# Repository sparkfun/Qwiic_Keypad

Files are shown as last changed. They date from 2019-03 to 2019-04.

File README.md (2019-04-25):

SparkFun Qwiic KeyPad - 12 Button
========================================

SparkFun Qwiic Keypad

[*SparkFun Qwiic Keypad - 12 Button (COM-15290)*](https://www.sparkfun.com/products/15290)

Keypads are very handy input devices, but who wants to tie up seven GPIO pins, wire up a handful of pull-up resistors, and write firmware that wastes valuable processing time scanning the keys for inputs? The SparkFun Qwiic Keypad comes fully assembled and makes the development process for adding a 12 button keypad easy. No voltage translation or figuring out which I2C pin is SDA or SCL, just plug and go! Utilizing our handy Qwiic system, no soldering is required to connect it to the rest of your system. However, we still have broken out 0.1"-spaced pins in case you prefer to use a breadboard.

Each of the keypad's 12 buttons has been labeled 1, 2, 3, 4, 5, 6, 7, 8, 9, 0, *, and # and has been formatted to into the same layout as a telephone keypad with each keypress resistance ranging between 10 and 150 Ohms. The Qwiic Keypad reads and stores the last 15 button presses in a First-In, First-Out (FIFO) stack, so you don’t need to constantly poll the keypad from your microcontroller. This information, then, is accessible through the Qwiic interface. The SparkFun Qwiic Keypad even has a software configurable I2C address so you can have multiple I2C devices on the same bus.

Repository Contents
-------------------

* **/Firmware** - The core sketch that runs Qwiic Keypad
* **/Hardware** - Eagle design files (.brd, .sch)

Documentation
--------------
* **[Hookup Guide](https://learn.sparkfun.com/tutorials/qwiic-keypad-hookup-guide)** - Hookup Guide for the SparkFun Qwiic Keypad - 12 Button
* **[Product Showcase - YouTube Video](https://youtu.be/QPRrk0tHk08)** - Product showcase video with Rob Reynolds introducing the product and showing a few examples.
* **[Library](https://github.com/sparkfun/SparkFun_Qwiic_Keypad_Arduino_Library)** - Arduino library for the SparkFun Qwiic Keypad - 12 Button
* **[Installing an Arduino Library](https://learn.sparkfun.com/tutorials/installing-an-arduino-library/)** - Basic instructions on installing an Arduino library

Product Versions
--------------
* [COM-15290](https://www.sparkfun.com/products/15290) - SparkFun version
* [SPX-14836](https://www.sparkfun.com/products/retired/14836) - SparkX version

License Information
-------------------

This product is _**open source**_! 

Please review the LICENSE.md file for license information.

If you have any questions or concerns on licensing, please contact technical support on our [SparkFun forums](https://forum.sparkfun.com/viewforum.php?f=152).

Please use, reuse, and modify these files as you see fit. Please maintain attribution to SparkFun Electronics and release under the same license.

Distributed as-is; no warranty is given.

- Your friends at SparkFun.

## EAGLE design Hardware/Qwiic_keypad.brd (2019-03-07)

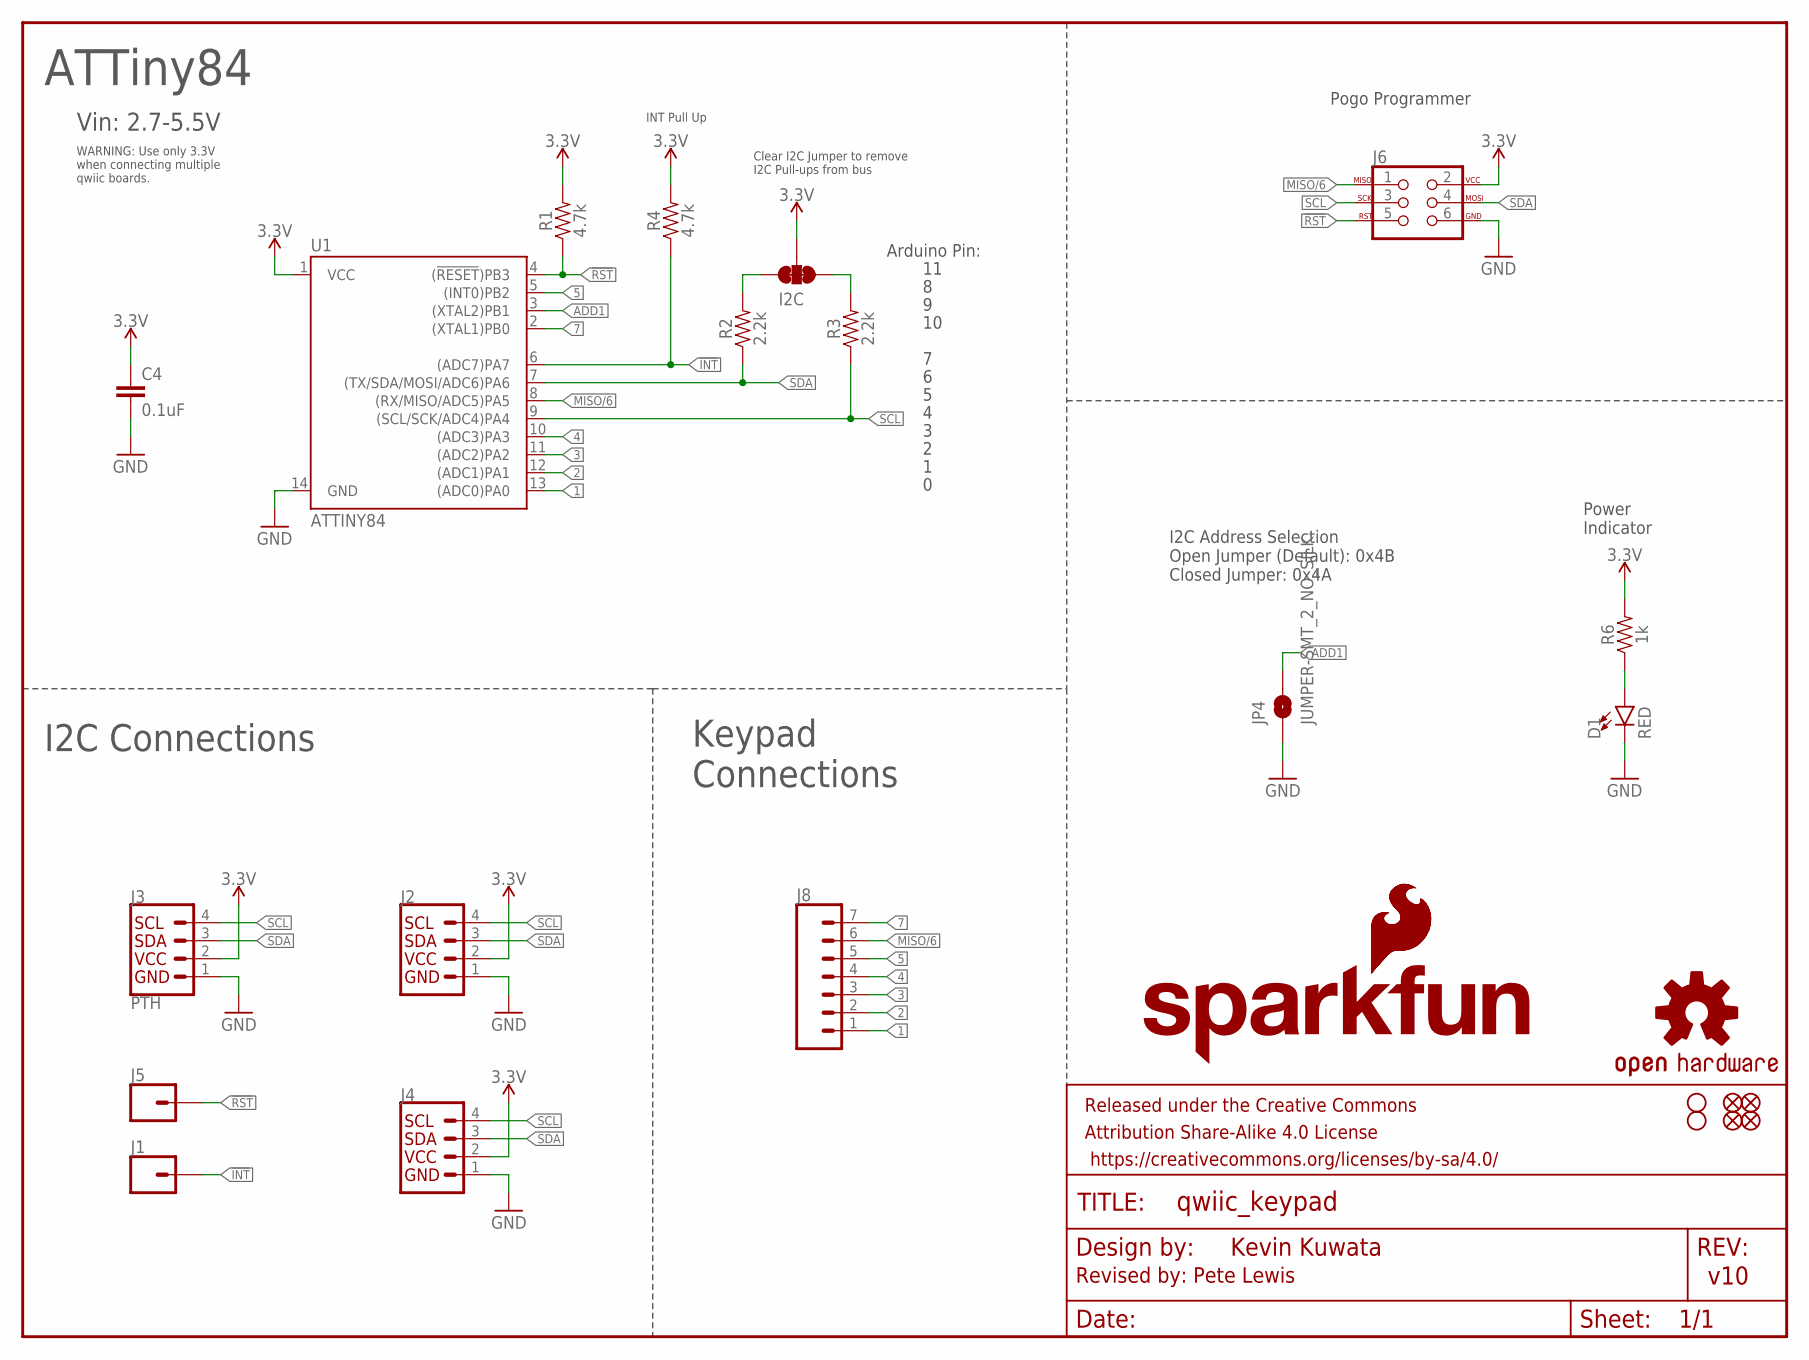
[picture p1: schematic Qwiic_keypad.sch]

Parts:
C4: 0.1uF; 0603
D1: RED; LED-0603
FRAME1: FRAME-LETTER; CREATIVE_COMMONS
H1, H2: STAND-OFF
I2C: JUMPER-SMT_3_2-NC_TRACE_SILK; SMT-JUMPER_3_2-NC_TRACE_SILK
J1, J5: CONN_01PTH_NO_SILK_YES_STOP; 1X01_NO_SILK
J2, J4: QWIIC_CONNECTORJS-1MM; JST04_1MM_RA
J3: PTH; 1X04_NO_SILK
J6: AVR_SPI_PROG_3X2TESTPOINTS; 2X3_TEST_POINTS
J8: CONN_07LOCK_NO_SILK; 1X07_LOCK_NO_SILK
JP1, JP2, JP3, JP6: FIDUCIALUFIDUCIAL; MICRO-FIDUCIAL
JP4: JUMPER-SMT_2_NO_SILK; SMT-JUMPER_2_NO_SILK
LOGO1: OSHW-LOGOMINI; OSHW-LOGO-MINI
LOGO2: SFE_LOGO_NAME_FLAME.1_INCH; SFE_LOGO_NAME_FLAME_.1
LOGO3: SFE_LOGO_FLAME.2_INCH; SFE_LOGO_FLAME_.2
R1, R4: 4.7k; 0603
R2, R3: 2.2k; 0603
R6: 1k; 0603
U1: ATTINY84; SO14

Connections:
1: J8.1, U1.13 ((ADC0)PA0)
2: J8.2, U1.12 ((ADC1)PA1)
3: J8.3, U1.11 ((ADC2)PA2)
3.3V: C4.1, I2C.2, J2.2, J3.2, J4.2, J6.2, R1.2, R4.2, R6.2, U1.1 (VCC)
4: J8.4, U1.10 ((ADC3)PA3)
5: J8.5, U1.5 ((INT0)PB2)
7: J8.7, U1.2 ((XTAL1)PB0)
!INT: J1.1, R4.1, U1.6 ((ADC7)PA7)
!RST: J5.1, J6.5, R1.1, U1.4 ((!RESET!)PB3)
ADD1: JP4.2, U1.3 ((XTAL2)PB1)
GND: C4.2, D1.C, J2.1, J3.1, J4.1, J6.6, JP4.1, U1.14 (GND)
MISO/6: J6.1, J8.6, U1.8 ((RX/MISO/ADC5)PA5)
unnamed: D1.A, R6.1
unnamed: I2C.3, R2.2
unnamed: I2C.1, R3.2
SCL: J2.4, J3.4, J4.4, J6.3, R3.1, U1.9 ((SCL/SCK/ADC4)PA4)
SDA: J2.3, J3.3, J4.3, J6.4, R2.1, U1.7 ((TX/SDA/MOSI/ADC6)PA6)

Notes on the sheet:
Kevin Kuwata
v10
I2C Address Selection Open Jumper (Default): 0x4B Closed Jumper: 0x4A
Power Indicator
Arduino Pin:
Revised by: Pete Lewis
INT Pull Up
Clear I2C Jumper to remove I2C Pull-ups from bus
ATTiny84
I2C Connections
Pogo Programmer
Vin: 2.7-5.5V
Keypad Connections
WARNING: Use only 3.3V when connecting multiple qwiic boards.

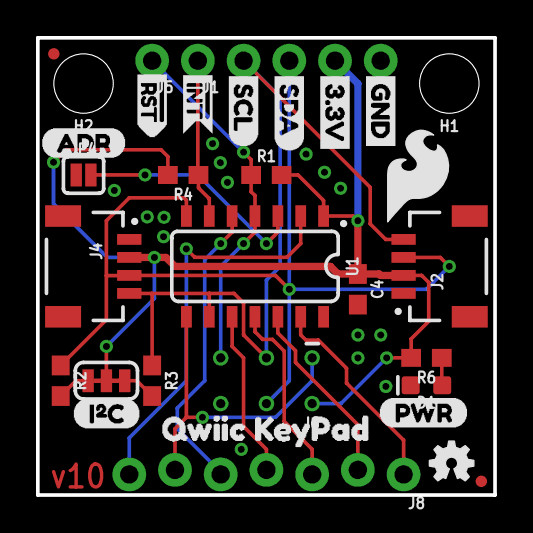
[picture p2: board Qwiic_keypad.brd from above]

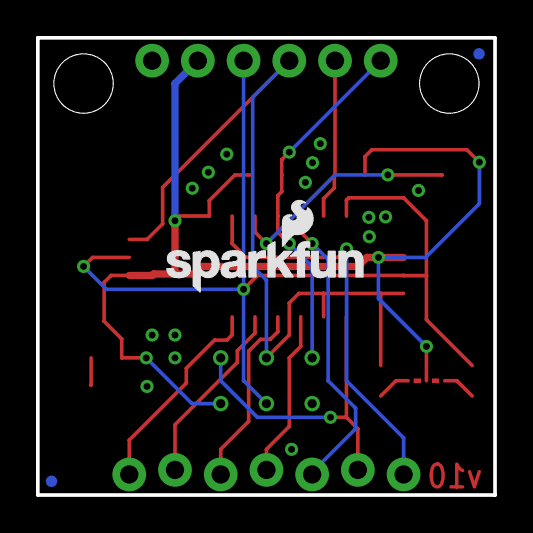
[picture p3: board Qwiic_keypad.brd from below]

Board: 2 copper layers, 25.4 x 25.4 mm, 37 parts (3 on the bottom side), 17 nets.

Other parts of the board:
U$3: 3.3V
U$4: GND
U$5: SDA
U$6: SCL
U$8: (PWR)
U$9: (I_SUPER2_C)
U$10: (ADR)
U$11: #RST>
U$12: #INT1
U$15: QWIIC_KEYPAD0

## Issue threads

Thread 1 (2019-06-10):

Problem running Qwiic Keypad on Adafruit Feather

seskindell, 2019-06-10:
Latest library get error message:

 'class TwoWire' has no member named 'end'

santaimpersonator, 2019-07-12:
Are you referring to this library:
https://github.com/sparkfun/SparkFun_Qwiic_Keypad_Arduino_Library

If so, the library was updated to take care of that. You just need to update the library in the Arduino IDE to the latest version.

santaimpersonator, 2019-12-28:
No response. Closing issue.

Closed 2019-12-28.

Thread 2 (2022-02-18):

I2C scan clobbers "registerNumber" value

dlkeng, 2022-02-18:

dlkeng, 2022-02-18:
In file **Qwiic_KeyPad.ino**, in the callback function **receiveEvent()**, the global variable **registerNumber**  is clobbered when an I2C scan is done with the Qwiic Keyboard attached to the I2C bus. This means a program expecting a response from a previously set register is unlikely to work as expected.

The fix is to check the **numberOfBytesReceived** parameter for zero and to not try to read a value from the Wire driver when that is the case.

lewispg228, 2022-02-23:
Hi @dlkeng ,
Thanks for finding this and filing the issue. I put a check into the receiveEvent() as you suggested. Could you please take a look at this?

https://github.com/sparkfun/Qwiic_Keypad/pull/3

Unfortunately, I don't have hardware in front of me right now. Would you be able to give this a shot with your setup? If not, I should be able to get my hands on some hardware in the next couple days.

Let me know and thanks again!
-Pete

dlkeng, 2022-02-23:
Pete,
The code looks good and is the same as I tested with.
However, I think you need to correct your associated comment because:
When **Wire.read()** has no data to return, it returns a **-1** (or 0xff into a byte variable), not zero. That's what I observed when I ran into this issue.

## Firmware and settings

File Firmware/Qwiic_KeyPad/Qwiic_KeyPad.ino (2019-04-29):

/*
  An I2C based KeyPad
  By: Nathan Seidle
  SparkFun Electronics
  Date: January 21st, 2018
  License: This code is public domain but you buy me a beer if you use this and we meet someday (Beerware license).

  Updated by: Pete Lewis
  SparkFun Electronics
  Date: March 16th, 2019

  Qwiic KeyPad is an I2C based key pad that records any button presses to a stack. To read buttons off the
  stack, the master must first command the keypad to load the fifo register, then read the fifo register.

  There is also an accompanying Arduino Library located here:
  https://github.com/sparkfun/SparkFun_Qwiic_Keypad_Arduino_Library

  Feel like supporting our work? Buy a board from SparkFun!
  https://www.sparkfun.com/products/14641

  To install support for ATtiny84 in Arduino IDE: https://github.com/SpenceKonde/ATTinyCore/blob/master/Installation.md
  This core is installed from the Board Manager menu
  This core has built in support for I2C S/M and serial
  If you have Dave Mellis' ATtiny installed you may need to remove it from \Users\xx\AppData\Local\Arduino15\Packages

  To support 400kHz I2C communication reliably ATtiny84 needs to run at 8MHz. This requires user to
  click on 'Burn Bootloader' before code is loaded.

*/

#include <Wire.h>

#include <EEPROM.h>

#include <avr/sleep.h> //Needed for sleep_mode
#include <avr/power.h> //Needed for powering down perihperals such as the ADC/TWI and Timers

#define LOCATION_I2C_ADDRESS 0x01 //Location in EEPROM where the I2C address is stored
#define I2C_ADDRESS_DEFAULT 75
#define I2C_ADDRESS_JUMPER 74

//This struc keeps a record of all the button presses
#define BUTTON_STACK_SIZE 15
struct {
  byte button; //Which button was pressed?
  unsigned long buttonTime; //When?
} buttonEvents[BUTTON_STACK_SIZE];
volatile byte newestPress = 0;
volatile byte oldestPress = 0;

const byte addr = 9; //Addr jumper
const byte interruptPin = 7; //Pin goes low when a button event is available

#include <Keypad.h>   // by Mark Stanley and Alexander Brevig 
                      // Click here to get the library: http://librarymanager/All#Keypad_matrix_style
                      // Note, if the search above doesn't work, try just "keypad" and find the correct one.
const byte ROWS = 4;
const byte COLS = 3;
char keys[ROWS][COLS] = {
  {'6', '4', '5'},
  {'9', '7', '8'},
  {'#', '*', '0'},
  {'3', '1', '2'}
};


#if defined(__AVR_ATmega328P__)
//Hardware connections while developing with an Uno
//Note, could not use pins 0 and 1 on uno, due to conflicting RX/TX debug
//Pin X on keypad is connected to Y:
//KeyPad               7, 6, 4, 2
byte rowPins[ROWS] = {10, 5, 3, 6};
//Keypad              5, 3, 1
byte colPins[COLS] = {8, 2, 4};

#elif defined(__AVR_ATtiny84__)
//Hardware connections for the final design
//Pin X on keypad is connected to Y:
//KeyPad               7, 6, 4, 2
byte rowPins[ROWS] = {10, 5, 3, 1};
//Keypad              5, 3, 1
byte colPins[COLS] = {8, 2, 0};

#endif
Keypad keypad = Keypad( makeKeymap(keys), rowPins, colPins, ROWS, COLS );

//Global variables
//-=-=-=-=-=-=-=-=-=-=-=-=-=-=-=-=-=-=-=-=-=-=-=-=-=-=-=-=-=-=-=-=-=-=-=-=-=-=-=-=-=-=-=-=-=-
//Variables used in the I2C interrupt so we use volatile

//This is the pseudo register map of the product. If user asks for 0x02 then get the 3rd
//byte inside the register map.
//5602/118 on ATtiny84 prior to conversion
//Approximately 4276/156 on ATtiny84 after conversion
struct memoryMap {
  byte id;                    // Reg: 0x00 - Default I2C Address
  byte firmwareMajor;         // Reg: 0x01 - Firmware Number
  byte firmwareMinor;         // Reg: 0x02 - Firmware Number
  byte fifo_button;         // Reg: 0x03 - oldest button (aka the "first" button pressed)
  byte fifo_timeSincePressed_MSB;  // Reg: 0x04 - time in milliseconds since the buttonEvent occured (MSB)
  byte fifo_timeSincePressed_LSB;  // Reg: 0x05 - time in milliseconds since the buttonEvent occured (LSB)
  byte updateFIFO;            // Reg: 0x06 - "command" from master, set bit0 to command fifo increment
  byte i2cAddress;            // Reg: 0x07 - Set I2C New Address (re-writable).
};

//These are the default values for all settings
volatile memoryMap registerMap = {
  .id = I2C_ADDRESS_DEFAULT, //Default I2C Address (0x20)
  .firmwareMajor = 0x01, //Firmware version. Helpful for tech support.
  .firmwareMinor = 0x00,
  .fifo_button = 0,
  .fifo_timeSincePressed_MSB = 0,
  .fifo_timeSincePressed_LSB = 0,
  .updateFIFO = 0,
  .i2cAddress = I2C_ADDRESS_DEFAULT,
};

//This defines which of the registers are read-only (0) vs read-write (1)
memoryMap protectionMap = {
  .id = 0x00,
  .firmwareMajor = 0x00,
  .firmwareMinor = 0x00,
  .fifo_button = 0x00,
  .fifo_timeSincePressed_MSB = 0x00,
  .fifo_timeSincePressed_LSB = 0x00,
  .updateFIFO = 0x01, // allow read-write on bit0 to "command" fifo increment update
  .i2cAddress = 0xFF,
};

//Cast 32bit address of the object registerMap with uint8_t so we can increment the pointer
uint8_t *registerPointer = (uint8_t *)&registerMap;
uint8_t *protectionPointer = (uint8_t *)&protectionMap;

volatile byte registerNumber; //Gets set when user writes an address. We then serve the spot the user requested.

//-=-=-=-=-=-=-=-=-=-=-=-=-=-=-=-=-=-=-=-=-=-=-=-=-=-=-=-=-=-=-=-=-=-=-=-=-=-=-=-=-=-=-=-=-=-

void setup(void)
{
  pinMode(addr, INPUT_PULLUP);
  pinMode(interruptPin, OUTPUT); //Goes low when a button event is on the stack

  //Disable ADC
  ADCSRA = 0;

  //Disble Brown-Out Detect
  MCUCR = bit (BODS) | bit (BODSE);
  MCUCR = bit (BODS);

  //Power down various bits of hardware to lower power usage
  //set_sleep_mode(SLEEP_MODE_PWR_DOWN);
  set_sleep_mode(SLEEP_MODE_IDLE);
  sleep_enable();

  readSystemSettings(); //Load all system settings from EEPROM

  startI2C(); //Determine the I2C address we should be using and begin listening on I2C bus

#if defined(__AVR_ATmega328P__)
  Serial.begin(115200);
  Serial.println("Qwiic Keypad");
  Serial.print("Address: 0x");
  Serial.print(registerMap.i2cAddress, HEX);
  Serial.println();
  Serial.print("EEPROM READ I2C Address:");
  Serial.print(EEPROM.read(LOCATION_I2C_ADDRESS), HEX);
  Serial.println();
  print_registerMap();
#endif

}

void loop(void)
{
  //Check for new key presses
  char key = keypad.getKey();
  if (key) {
    //Check for buffer overrun
    // if oldest press is trailing just one behind, then we also will need to increment
    if (oldestPress == (newestPress + 1)) oldestPress++;
    if ( (newestPress == (BUTTON_STACK_SIZE - 1)) && (oldestPress == 0) ) oldestPress++;
    if (oldestPress == BUTTON_STACK_SIZE) oldestPress = 0; //still need to wrap if it happens

    newestPress++;
    if (newestPress == BUTTON_STACK_SIZE) newestPress = 0; //Wrap variable

    buttonEvents[newestPress].button = key;
    buttonEvents[newestPress].buttonTime = millis();

    digitalWrite(interruptPin, HIGH); //Set Int HIGH, to cause a FALLING edge later
    //Note, this will be set LOW again at bottom of main loop.
    //This FALLING edge is useful for hardware INT on your project's master IC.

#if defined(__AVR_ATmega328P__)
    Serial.print(char(buttonEvents[newestPress].button));
    print_registerMap();
    print_buttonEvents();
#endif
  }

  //Set interrupt pin as needed
  if (newestPress != oldestPress)
    digitalWrite(interruptPin, LOW); //We have events on the stack!
  else
    digitalWrite(interruptPin, HIGH); //No button events to report

  sleep_mode(); //Stop everything and go to sleep. Wake up if I2C event occurs.
}

//When Qwiic Keypad receives data bytes from Master, this function is called as an interrupt
//(Serves rewritable I2C address and updateFifo command)
void receiveEvent(int numberOfBytesReceived)
{
  registerNumber = Wire.read(); //Get the memory map offset from the user

  //Begin recording the following incoming bytes to the temp memory map
  //starting at the registerNumber (the first byte received)
  for (byte x = 0 ; x < numberOfBytesReceived - 1 ; x++)
  {
    byte temp = Wire.read(); //We might record it, we might throw it away

    if ( (x + registerNumber) < sizeof(memoryMap))
    {
      //Clense the incoming byte against the read only protected bits
      //Store the result into the register map
      *(registerPointer + registerNumber + x) &= ~*(protectionPointer + registerNumber + x); //Clear this register if needed
      *(registerPointer + registerNumber + x) |= temp & *(protectionPointer + registerNumber + x); //Or in the user's request (clensed against protection bits)
    }
  }

  recordSystemSettings();
}

//Send back a number of bytes via an array, max 32 bytes
//When KeyPad gets a request for data from the user, this function is called as an interrupt
//The interrupt will respond with different types of data depending on what response state we are in
//The user sets the response type based on bytes sent to KeyPad
void requestEvent()
{
  if (registerMap.updateFIFO & (1 << 0))
  {
    // clear command bit
    registerMap.updateFIFO &= ~(1 << 0);

    // update fifo, that is... copy oldest button (and buttonTime) into fifo register (ready for reading)
    loadFifoRegister();
  }

#if defined(__AVR_ATmega328P__)
  print_registerMap();
  print_buttonEvents();
#endif

  Wire.write((registerPointer + registerNumber), sizeof(memoryMap) - registerNumber);
}

//Take the FIFO button press off the stack and load it into the fifo register (ready for reading)
void loadFifoRegister()
{
  if (oldestPress != newestPress)
  {
    oldestPress++;
    if (oldestPress == BUTTON_STACK_SIZE) oldestPress = 0;

    registerMap.fifo_button = buttonEvents[oldestPress].button;

    unsigned long timeSincePressed = millis() - buttonEvents[oldestPress].buttonTime;

    registerMap.fifo_timeSincePressed_MSB = (timeSincePressed >> 8);
    registerMap.fifo_timeSincePressed_LSB = timeSincePressed;
  }
  else
  {
    //No new button presses. load blank records
    registerMap.fifo_button = 0;
    registerMap.fifo_timeSincePressed_MSB = 0;
    registerMap.fifo_timeSincePressed_LSB = 0;
  }
}

//Reads the current system settings from EEPROM
//If anything looks weird, reset setting to default value
void readSystemSettings(void)
{
  //Read what I2C address we should use
  registerMap.i2cAddress = EEPROM.read(LOCATION_I2C_ADDRESS);
  if (registerMap.i2cAddress == 255)
  {
    registerMap.i2cAddress = I2C_ADDRESS_DEFAULT; //By default, we listen for I2C_ADDRESS_DEFAULT
    EEPROM.write(LOCATION_I2C_ADDRESS, registerMap.i2cAddress);
  }
}

//Begin listening on I2C bus as I2C slave using the global variable registerMap.i2cAddress
void startI2C()
{
  Wire.end(); //Before we can change addresses we need to stop

  if (digitalRead(addr) == HIGH) //Default is HIGH, the jumper is open
    Wire.begin(registerMap.i2cAddress); //Start I2C and answer calls using address from EEPROM
  else
    Wire.begin(I2C_ADDRESS_JUMPER); //Force address to I2C_ADDRESS_JUMPER if user has closed the solder jumper

  //The connections to the interrupts are severed when a Wire.begin occurs. So re-declare them.
  Wire.onReceive(receiveEvent);
  Wire.onRequest(requestEvent);
}

#if defined(__AVR_ATmega328P__)
void print_registerMap()
{
  Serial.println("registerMap contents:");
  for (byte i = 0 ; i < sizeof(memoryMap) ; i++)
  {
    Serial.println(*(registerPointer + i));
  }
}

void print_buttonEvents()
{
  Serial.println("buttonEvents[] contents: button, buttonTime");
  for (byte i = 0 ; i < BUTTON_STACK_SIZE ; i++)
  {
    Serial.print("[");
    Serial.print(i);
    Serial.print("]:");
    Serial.print(char(buttonEvents[i].button));
    Serial.print(", ");
    Serial.println(buttonEvents[i].buttonTime);
  }
}
#endif

//If the current setting is different from that in EEPROM, update EEPROM
void recordSystemSettings(void)
{
  //I2C address is byte
  byte i2cAddr;

  //Error check the current I2C address
  if (registerMap.i2cAddress < 0x08 || registerMap.i2cAddress > 0x77)
  {
    //User has set the address out of range
    //Go back to defaults
    registerMap.i2cAddress = I2C_ADDRESS_DEFAULT;
  }

  //Read the value currently in EEPROM. If it's different from the memory map then record the memory map value to EEPROM.
  EEPROM.get(LOCATION_I2C_ADDRESS, i2cAddr);
  if (i2cAddr != registerMap.i2cAddress)
  {
    EEPROM.write(LOCATION_I2C_ADDRESS, registerMap.i2cAddress);
    startI2C(); //Determine the I2C address we should be using and begin listening on I2C bus
    //Serial.print("New Address: 0x");
    //Serial.println(registerMap.i2cAddress, HEX);
  }
}

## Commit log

2019-02-28 copying over sparkX repo
    note, not including hardware production panel files, those will need to be recreated anyways with this new revision.
    [Qwiic_keypad.brd, Qwiic_keypad.sch]
2019-02-28 updating hardware
    -SFE logo in schematic (w/ slight re-arrange to fit)
    -changed version in sch (and brd) to v10
    -bumped traces up from 6 mils to 8 mils.
    -bumped vias up from 12 mils to 15 mils.
    -switched to "sfe tight" drc
    -minor trace nudgeing to avoid clearance warnings.
    -increased "pass through" 3.3V trace to 16 mils. added more GND vias.
    [Qwiic_keypad.brd, Qwiic_keypad.sch]
2019-03-06 Locking footprint on 1x7 connector to keypad
    This will help with holding position during selective solder
    [Qwiic_keypad.brd, Qwiic_keypad.sch]
2019-03-06 added INT pullup resistor
    [Qwiic_keypad.brd, Qwiic_keypad.sch]
2019-03-07 hardware review changes
    beef up trace to 3.3V PTH header breakout as well.
    Nudged I2C label up to match power label hieght.
    ATTINY84 polarity mark fill in library
    Logo up to .2 size flame.
    Schematic note for I2C pullup jumper
    Updated ATTiny device (just the symbol changed, but needed to "replace" due to new pin names).
    nudged LED lower to ensure mask gap from nearby resistor
    [Qwiic_keypad.brd, Qwiic_keypad.sch]
2019-03-07 double-check (my run) fixes
    added SS path on 48.
    package update on address jumper - to 8 mil width on silk outline.
    library update to SFE library on I2C jumper (was sparkx lbr).
    some minor routing tweaks to allow more gnd flow
    [Qwiic_keypad.brd, Qwiic_keypad.sch]
2019-03-12 Fixed overflow issues
    Discovered a problem: If you didn't read the keypad for a long time, and the user had input more than 15 buttons, there was an overflow error.
    It had to do with the incrementing of oldest and newest press variables. The incrementations needed to be ahead of the read/write actions. We also needed some more conditionals to handle the "trailing just one behind scenario".
    Also, started to add in the register map stuff.
    [Qwiic_KeyPad.ino]
2019-03-16 update fifo and read button working
    also, more debug while devving on an Uno.
2019-03-18 I2C change working properly now
    It was not updating the I2C address (in the registerMap.i2cAddress) correctly in the readSystemSettings() function. Now it is.
    Also, removed the old (and now unused) variable "setting_i2c_address".
    Added some more debug at setup when devving on an Uno - EEPROM read, for sanity.
    [Qwiic_KeyPad.ino]
2019-03-18 correcting device name in #elif for pin definitions
    it is in fact an ATTiny84
    [Qwiic_KeyPad.ino]
2019-03-21 interrupt pin correction for FALLING detection
    When a new button is pressed, I added this:
    digitalWrite(interruptPin, HIGH); //Set Int HIGH, to cause a FALLING edge later
    //Note, this will be set LOW again at bottom of main loop.
    //This FALLING edge is useful for hardware INT on your project's master IC.
    With this, when a new button is pressed, it causes a falling edge on int. Great when using hardware interrupt on your controller IC.
    [Qwiic_KeyPad.ino]
2019-04-29 Added library manager link (with search) to correct keypad library
    for easily finding the correct library you need to compile this firmware. Note, the search actually uses words that are unique to the library "sentence".
    [Qwiic_KeyPad.ino]

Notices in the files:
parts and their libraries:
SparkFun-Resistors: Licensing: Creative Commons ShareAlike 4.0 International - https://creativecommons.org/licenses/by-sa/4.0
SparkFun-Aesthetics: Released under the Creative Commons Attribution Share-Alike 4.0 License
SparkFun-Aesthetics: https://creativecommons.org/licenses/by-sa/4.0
